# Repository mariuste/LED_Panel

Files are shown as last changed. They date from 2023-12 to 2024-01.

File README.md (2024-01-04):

# LED light panel with adjustable color temperature
# Project Parameters
Name: "LED light panel with adjustable color temperature"
Description: "USB-C powered LED Light with adjustable brigthness and color temperature"
Short Name: "LED Panel"
Github Name: "LED_Panel"
PCB Name: "LED_Panel"

# Description
/TODO/

# ToDos
- create requirements
- define critical components (MCU, poti, Mosfets, emc)
- define mechanical constraints (dimensios glass, mounting priciple, screw positios)
- create 3D Mockup
- create schematic
- create layout

# Specification for LED_board

## Usage
- plug in -> LED will go to last setting (maybe slight fade) if sw is on
- on/off switch integrated in poti 1
- turn poti 1 for adjusting brightness
- turn poti 2 for adjusting light color

## HMI
- Large Pot for brightness and on/off
- Small Poti for light color

## LEDs
- LEDs can be divided every 13mm; 608 LED per meter (304 per color); 22W per meter
- three rows of 130mm strips

## Core Function
- create soft light and adjust light color

## Software
- brightness and light color controlled via two PWM MOSFETs

### Fault handling
- not enough voltage/power from USB-C: light pattern to indicate error

## Software
- loop: read USB-PD for available power, read poti, set brightness and color

## Power concept
- LEDs: 22W/m -> 3 * 130mm * 22W = 8.58W // 715mA@12V -> with 80%DCDC: 686mA@15V / 515mA@20V
- USB-PD board set to 15V, >= 1.0A (15W)
- DC/DC to regulate 15V to 12V, 1A
- when switch is off-> reset USB PD

## Mechanics
- acryl from https://expresszuschnitt.de (170mm * 90mm * 4mm, rounded corner of 8mm radius)
- M4 mounting to enclosure
- M4 mounting for mounting plate (75 * 75)

# Part selection
- MCU: STM32L011F3U6TR
- Poti /w switch: P091S-FC20BR10K
- Poti /wo Switch: P091N-FC25BR10K
- LED: COB44-079  by LED24
- USB: UJC-HP2-3-SMT-TR

- Regulator: TPS62932DRLR
- Inductor: 7447709150

- MOSFET: SI1308EDL-T1-GE3
- LDO: NCP716MT30TBG

- USBPD: STUSB4500

obsolet (could replace DC/DC and MOSFET):
- LED-driver: TPS92200D2RXLR ? AL8861Y-13 ? IS31LT3350-V1SDLS2-TR

# Preliminary pinmapping
## USB-PD IC
- SDA PB7
- SCL PB6
- reset PD PA9 (OUT)
- alarm in PA10 (IN)

## Debuging (GPIOS)
- GPIO1 PC14
- GPIO2 PC15

## Debugging (SWD)
- SWDIO PA13
- SWCLK PA14

## Poti Readback (Vref: 1.224V)
- Poti1 PA0 (AIN0)
- Poti2 PA4 (AIN4)

## PWM outputs
- LED1 PA5 (TIM2_CH1)
- LED2 PA1 (TIM2_CH2)

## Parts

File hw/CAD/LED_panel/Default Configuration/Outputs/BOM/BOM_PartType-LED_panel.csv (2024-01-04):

Quantity | Designator | Type | Comment | Description | Manufacturer | Manufacturer Part Number | LibRef | Supplier 1 | Supplier Part Number 1
3 | C200, C201, C202 | Capacitor | C 4.7uF 0805 50V | CAP CER 4.7UF 50V X5R 0805 | Samsung Electro-Mechanics | CL21A475KBQNNNE | CAP_4.7uF_50V_0805 | Digi-Key | 1276-1248-1-ND
4 | C203, C301, C400, C402 | Capacitor | C 100nF 0402 50V | CAP CER 0.1UF 50V X7R 0402 | Murata Electronics | GRM155R71H104KE14J | CAP_100nF_50V_0402 | Digi-Key | 490-13342-1-ND
4 | C204, C205, C206, C300 | Capacitor | C 1uF 0402 25V | CAP CER 1UF 25V X5R 0402 | Taiyo Yuden | TMK105BJ105MV-F | CAP_1uF_25V_0402 | Digi-Key | 587-3245-1-ND
1 | C302 | Capacitor | C 100nF 0402 10V | CAP CER 0.1UF 10V X5R 0402 | Samsung Electro-Mechanics | CL05A104MP5NNNC | CAP_100nF_10V_0402 | Digi-Key | 1276-1443-1-ND
1 | C401 | Capacitor | C 10uF 0805 50V | CAP CER 10UF 50V X5R 0805 | Murata Electronics | GRM21BR61H106KE43K | CAP_10uF_50V_0805 | Digi-Key | 490-GRM21BR61H106KE43KTR-ND
1 | C403 | Capacitor | C 47pF 0402 25V | CAP CER 47PF 25V C0G/NP0 0402 | KEMET | C0402C470J3GAC7867 | CAP_47pF_25V_0402 | Digi-Key | 399-C0402C470J3GAC7867CT-ND
1 | C404 | Capacitor | C 33nF 0402 50V | CAP CER 0.033UF 50V X7R 0402 | Murata Electronics | GCM155R71H333KE02J | CAP_33nF_50V_0402 | Digi-Key | 490-GCM155R71H333KE02JTR-ND
1 | C405 | Capacitor | C 47uF 1206 25V | CAP CER 47UF 25V X5R 1206 | Murata Electronics | GRM31CR61E476ME44K | CAP_47uF_25V_1206 | Digi-Key | GRM31CR61E476ME44K
1 | D100 | Diode | BAS20LT3G | DIODE GP 200V 200MA SOT23-3 | onsemi | BAS20LT3G | D_LL_200V_200mA | Digi-Key | BAS20LT3GOSCT-ND
2 | D200, D201 | Diode, TVS | TVS 41V | TVS DIODE 22VWM 41VC 1610 | STMicroelectronics | ESDA25P35-1U1M | D_SCH_41V_35A | Digi-Key | 497-16913-1-ND
1 | D202 | Diode, TVS | TVS_4 5V | TVS DIODE 5VWM 12.5VC SOT23-6 | Comchip Technology | CPDT6-5V0UPC-HF | D_TVS_U4_12V5 | Digi-Key | 641-1829-1-ND
2 | D203, D204 | Diode, LED | LED G | LED GREEN DIFFUSED 0603 SMD | OSRAM Opto Semiconductors Inc. | LT Q39G-Q1OO-25-1 | D_LED_Green_0603 | Digi-Key | 475-3442-1-ND
1 | D205 | Diode, LED | LED R | LED RED DIFFUSED 0603 SMD | OSRAM Opto Semiconductors Inc. | LS Q976-NR-1 | D_LED_Red_0603 | Digi-Key | 475-2512-1-ND
1 | IC200 | IC, Regulator | NCP716MT30TBG | IC REG LINEAR 3V 80MA 6WDFN | onsemi | NCP716MT30TBG | IC_Reg_NCP716MT30TBG | Digi-Key | 488-NCP716MT30TBGTR-ND
1 | IC201 | IC | STUSB4500 | IC USB CONTROLLER I2C 24QFN | STMicroelectronics | STUSB4500QTR | IC_STUSB4500 | Digi-Key | 497-18060-2-ND
1 | IC300 | IC, MCU | STM32L011F3U6 | IC MCU 32BIT 8KB FLASH 20UFQFPN | STMicroelectronics | STM32L011F3U6TR | IC_MCU_STM32L011F3U6 | Digikey | 497-18800-2-ND
1 | IC400 | IC, Regulator | TPS62932 | IC REG BUCK ADJ 2A SOT583 | Texas Instruments | TPS62932DRLR | IC_Reg_TPS62932DRLR | Digi-Key | 296-TPS62932DRLRTR-ND
1 | J200 | Connector | USB_C PWR | TYPE C, 20 VDC, 3 A, RIGHT ANGLE | CUI Devices | UJC-HP2-3-SMT-TR | J_USB-C_3 | Digi-Key | 2223-UJC-HP2-3-SMT-TR-ND
1 | J300 | Connector | 5x2 | CONN HEADER SMD 10POS 1.27MM | Sullins Connector Solutions | GRPB052VWQS-RC | J_MH5x2_1.27 | Digi-Key | S9012E-05-ND
1 | L200 | Inductor | L 1.2uH 3.9A | FIXED IND 1.2UH 3.9A 36 MOHM SMD | Würth Elektronik | 74438336012 | L_1.2uH_3.9A | Digi-Key | 732-5694-1-ND
2 | L201, L202 | Inductor, Ferrite | L Ferrite 100R 4A | FIXED IND 100 4000MA 1206 | Eaton - Electronics Division | MFBM1V3216-101-R | L_100R_4A | Digi-Key | 283-MFBM1V3216-101-RCT-ND
1 | L400 | Inductor | L 15uH 6.5A | FIXED IND 15UH 6.5A 26 MOHM SMD | Würth Elektronik | 7447709150 | L_15uH_6.5A | Digi-Key | 732-7447709150TR-ND
2 | P100, P101 | Transistor | P NMOS 30V 600mA | MOSFET N-CH 30V 600MA SC70-3 | Vishay Siliconix | SI1302DL-T1-E3 | P_NCH_30V_280mW | Digi-Key | SI1302DL-T1-E3CT-ND
1 | P102 | Transistor | P_NCH_50V_150mW | MOSFET N-CH 50V 200MA UMT3F | Rohm Semiconductor | RU1J002YNTCL | P_NCH_50V_150mW | Digi-Key | RU1J002YNTCLCT-ND
1 | P200 | Transistor | P PMOS 30V 6A | MOSFET P-CH 30V 6A SOT23F | Toshiba Semiconductor and Storage | SSM3J372R,LF | P_PCH_30V_1W | Digi-Key | SSM3J372RLFCT-ND
4 | R100, R101, R102, R103 | Resistor | R 180R 0603 | RES 180 OHM 1% 1/10W 0603 | Stackpole Electronics Inc | RMCF0603FT180R | R_180R_0603 | Digi-Key | RMCF0603FT180RCT-ND
5 | R104, R106, R201, R207, R213 | Resistor | R 1k8 0402 | RES 1.8K OHM 1% 1/16W 0402 | Stackpole Electronics Inc | RMCF0402FT1K80 | R_1k8_0402 | Digi-Key | RMCF0402FT1K80CT-ND
12 | R105, R107, R108, R110, R208, R209, R210, R211, R214, R215, R301, R404 | Resistor | R 7k15 0402 | RES 7.15K OHM 1% 1/16W 0402 | Stackpole Electronics Inc | RMCF0402FT7K15 | R_7k15_0402 | Digi-Key | RMCF0402FT7K15CT-ND
7 | R109, R202, R206, R212, R300, R302, R403 | Resistor | R 100k 0402 | RES 100K OHM 5% 1/16W 0402 | YAGEO | RC0402JR-07100KL | R_100k_0402 | Digi-Key | 311-100KJRCT-ND
5 | R111, R204, R303, R304, R305 | Resistor | R 100R 0402 | RES 100 OHM 1% 1/16W 0402 | Stackpole Electronics Inc | RMCF0402FT100R | R_100R_0402 | Digi-Key | RMCF0402FT100RCT-ND
9 | R200, R203, R205, R216, R217, R218, R400, R401, R402 | Resistor | R 0R0 0402 | RES 0 OHM JUMPER 1/16W 0402 | Stackpole Electronics Inc | RMCF0402ZT0R00 | R_0R0_0402 | Digi-Key | RMCF0402ZT0R00CT-ND
1 | RT100 | other, Poti | 10k | POT 10K OHM 1/20W PLASTIC LINEAR | TT Electronics/BI | P091S-FC20BR10K | RT_10k_SW_V | Digi-Key | 987-1283-ND
1 | RT101 | other, Poti | 10k | POT 10K OHM 1/20W PLASTIC LINEAR | TT Electronics/BI | P091N-FC25BR10K | RT_10k_V | Digi-Key | 987-1279-ND
3 | X100, X101, X102 | other | LED Strip | revoART, 12V COB LED Streifen - einstellbare Farbtemperatur - alle 1,3cm teilbar - 10mm breit | revoART | COB44-076 | LED_Strip_2WH_131mm | LED24 | COB44-076

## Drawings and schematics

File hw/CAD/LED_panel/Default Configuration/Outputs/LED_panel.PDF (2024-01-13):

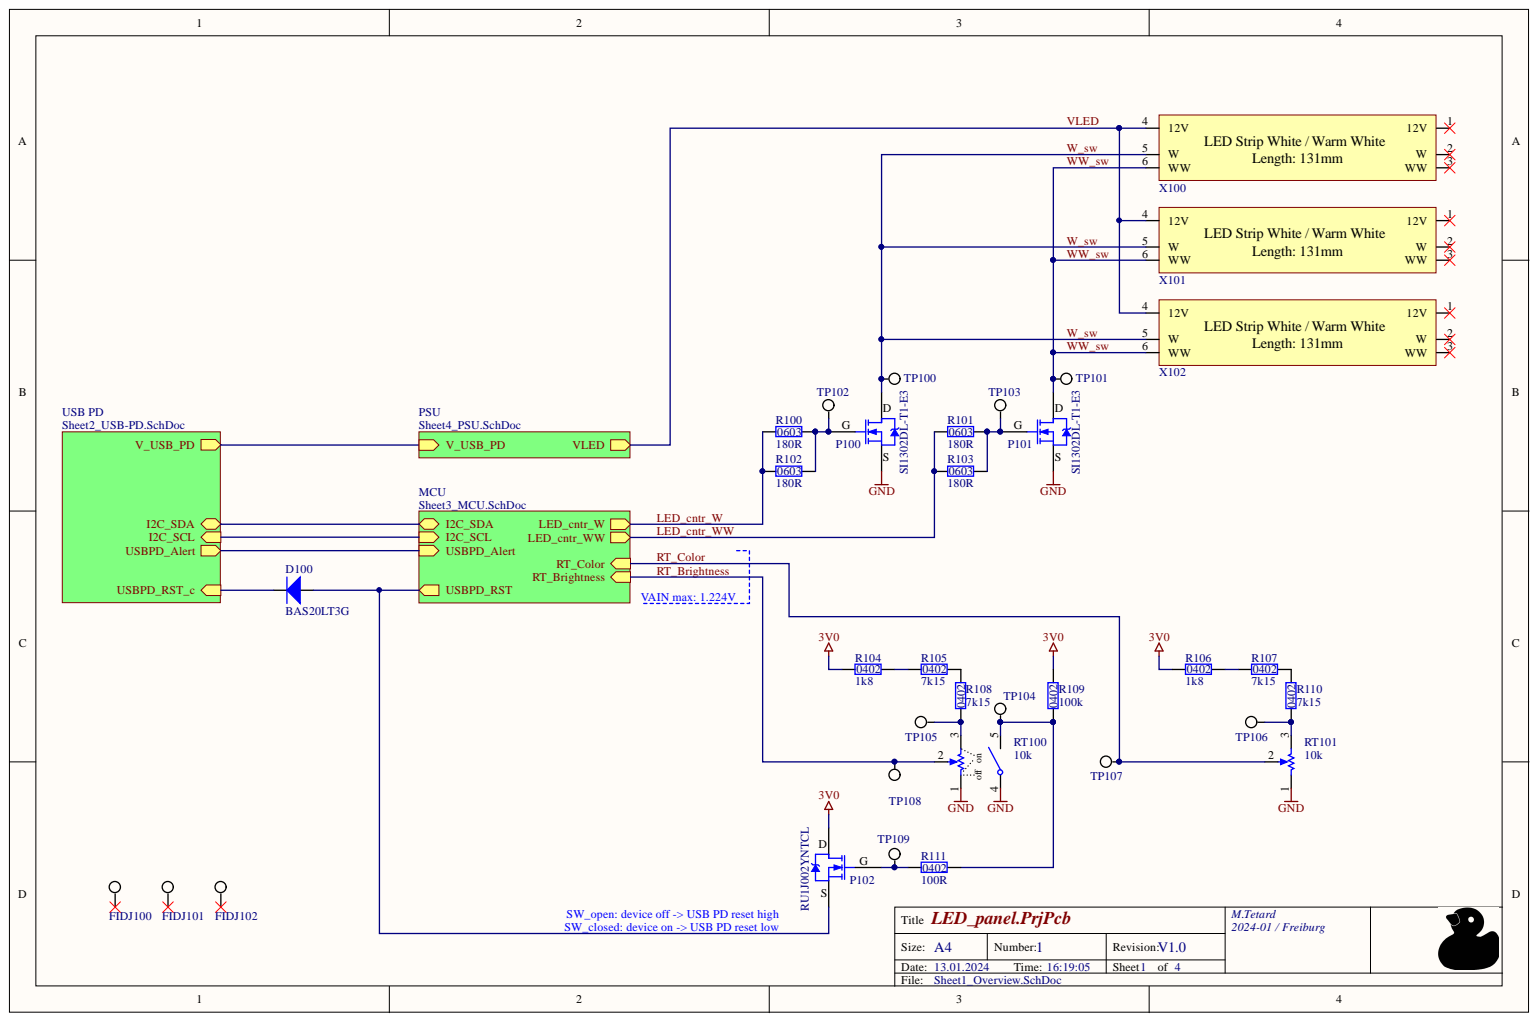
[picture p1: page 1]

W_sw | | W 5
WW_sw | | | WW 6

LED Strip White / Warm White

W_sw

RT_Brightness

VAIN max: 1.224V

SW_open: device off -> USB PD reset high
SW_closed: device on -> USB PD reset low

LED_panel.PrjPcb Title | M.Tetard 2024-01 / Freiburg

A4 Size: | 1 Number: | V1.0 Revision:
Date: 13.01.2024 Time: 16:19:05 | | Sheet of

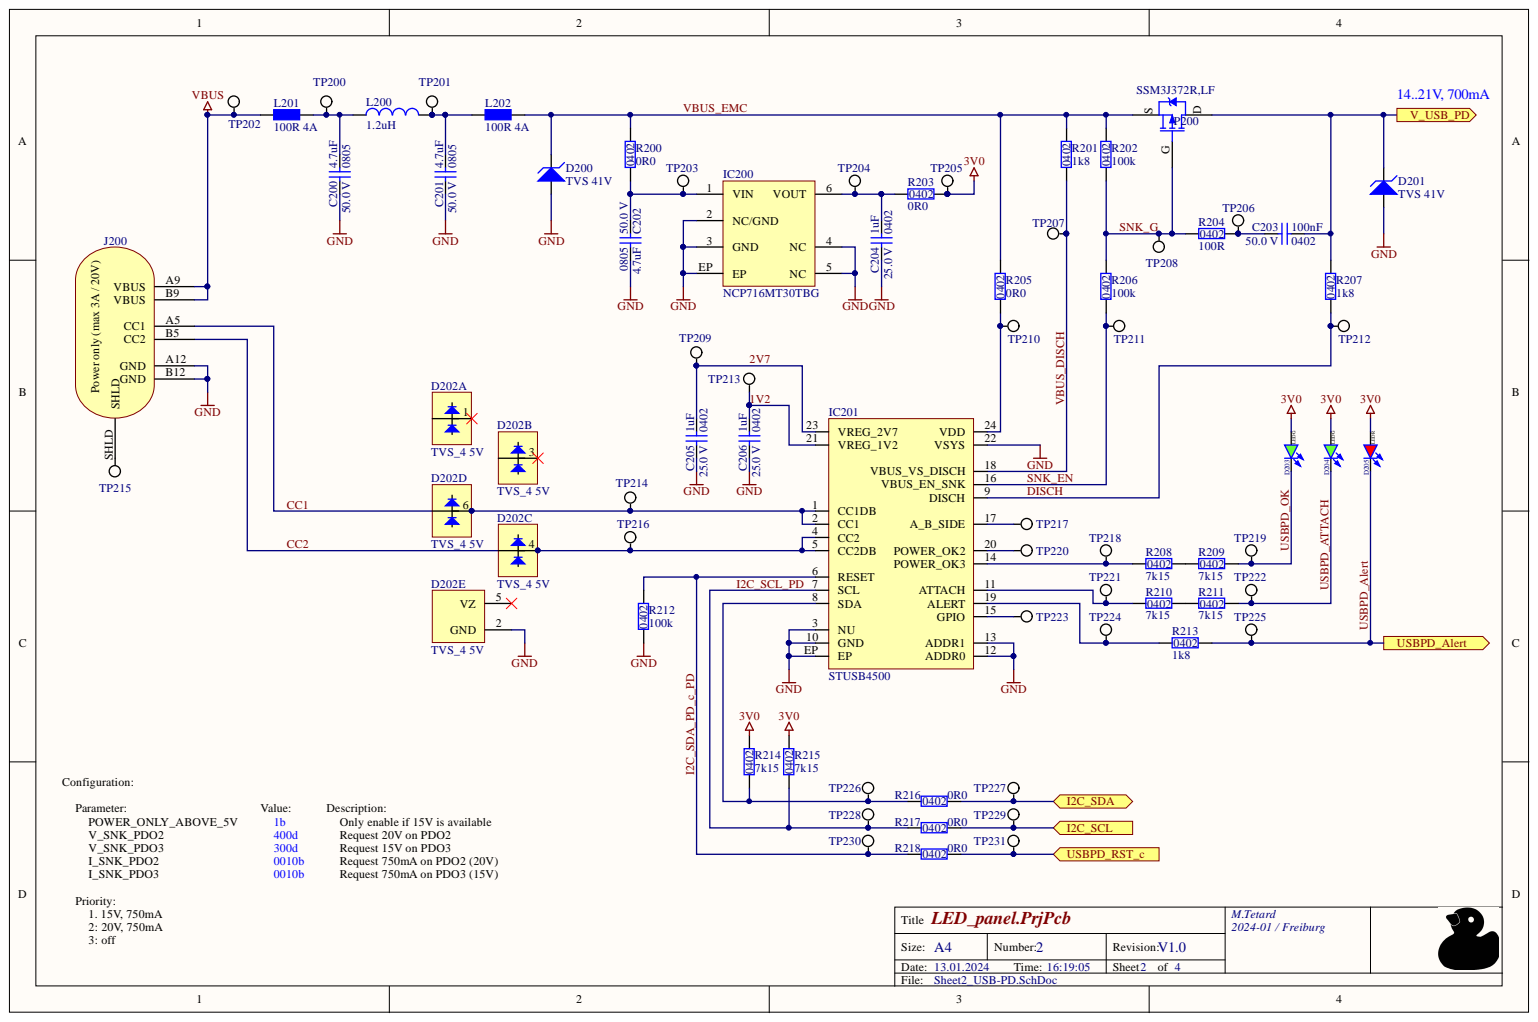
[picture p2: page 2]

NC/GND 2 | 0402

RESET 6

I2C_SCL_PD

SDA 8

GND 10

Description:
Only enable if 15V is available

LED_panel.PrjPcb Title | M.Tetard 2024-01 / Freiburg

A4 Size: | 2 Number: | V1.0 Revision:

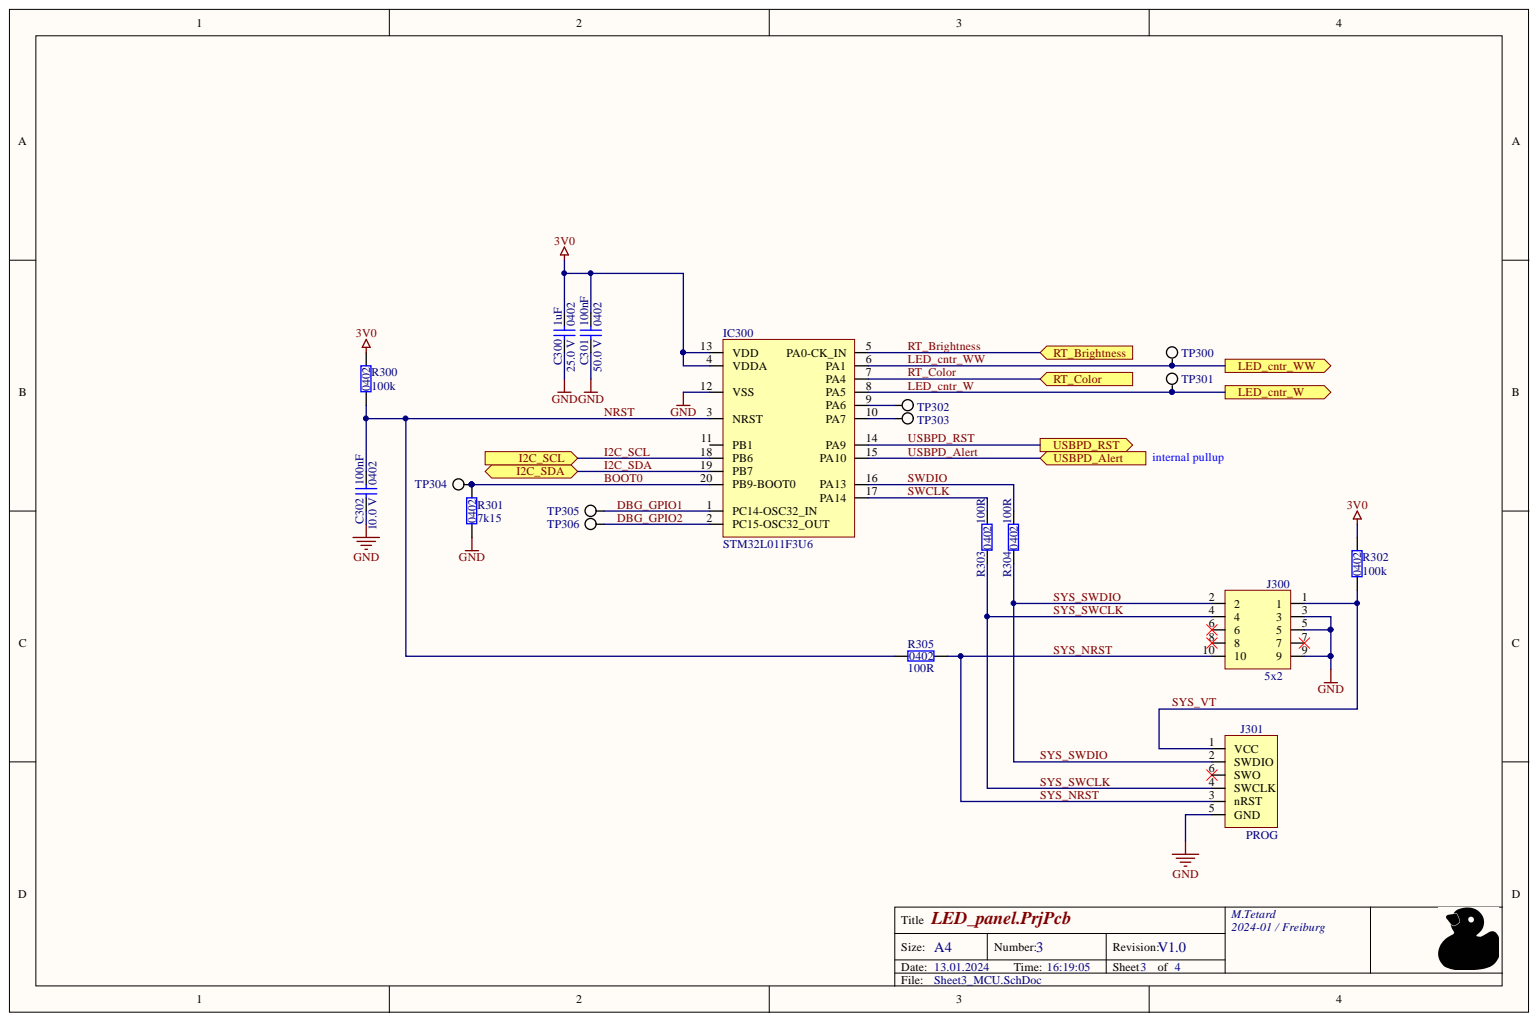
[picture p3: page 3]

I2C_SCL I2C_SCL I2C_SDA I2C_SDA BOOT0 | PB1 11 PA9 PA10 PA13 PA14 | 14 15 16

PC14-OSC32_IN 1 PC15-OSC32_OUT 2 | | 17 | SWCLK

SYS_SWCLK

SYS_NRST

SYS_SWDIO | SYS_VT | GND

SWDIO 2

LED_panel.PrjPcb Title | M.Tetard 2024-01 / Freiburg

A4 Size: | 3 Number: | V1.0 Revision:

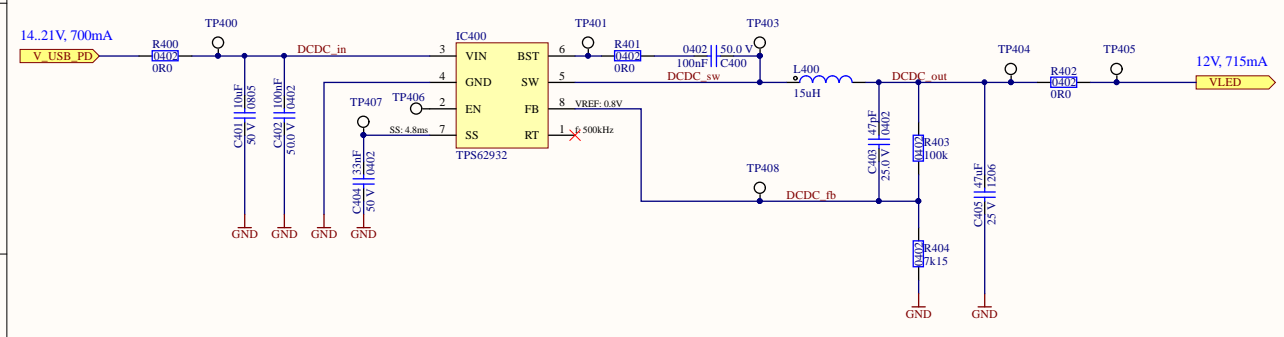
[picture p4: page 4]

7 | | 1 | f: 500kHz TP4 0 8 DCDC_fb

LED _p T i t l e | M.Tet a rd 2 0 2 4-0 1 / F rei b u rg

A4 Size: | N umber: | Rev i s i o n :

3.0 1.2 T ime: : : | | Sheet o f

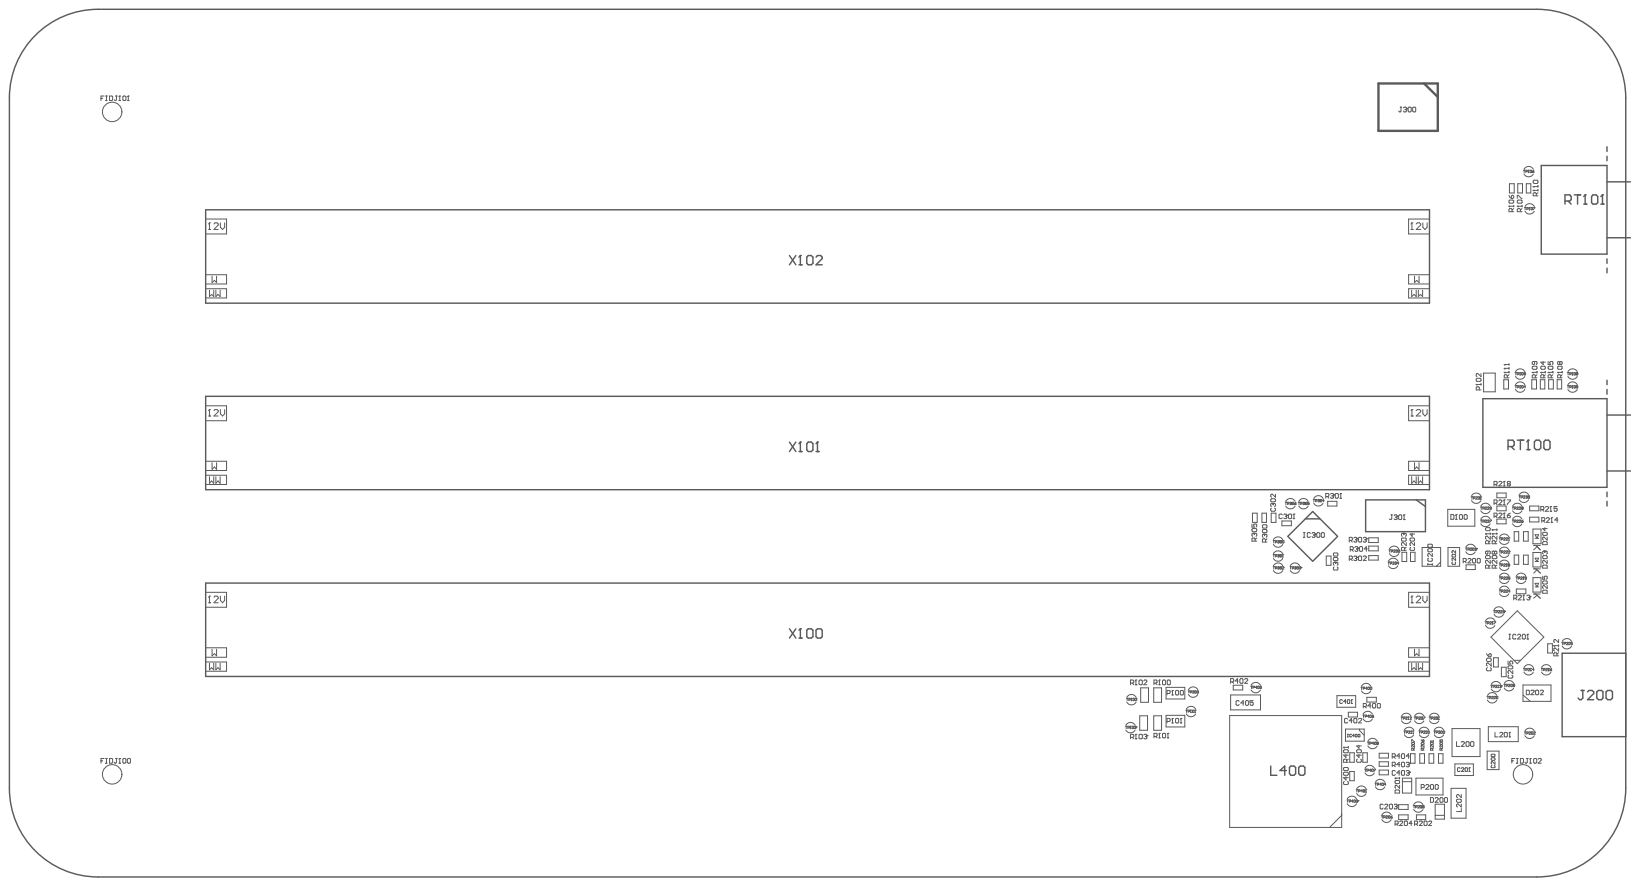
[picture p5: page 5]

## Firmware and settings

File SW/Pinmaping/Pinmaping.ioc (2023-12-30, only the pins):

Mcu.UserName=STM32L011F3Ux
PA0-CK_IN.Signal=ADC_IN0
PA1.Signal=S_TIM2_CH2
PA10.Signal=GPIO_Input
PA13.Signal=SYS_SWDIO
PA14.Signal=SYS_SWCLK
PA4.Signal=ADC_IN4
PA5.Signal=S_TIM2_CH1
PA9.Signal=GPIO_Output
PB6.Signal=I2C1_SCL
PB7.Signal=I2C1_SDA
PC14-OSC32_IN.Signal=GPIO_Input
PC15-OSC32_OUT.Signal=GPIO_Input

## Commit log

2023-12-26 designed device
2023-12-27 initial draft
    [LED_panel.PrjPcb, Sheet1_Overview.SchDoc, Sheet2_USB-PD.SchDoc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]
2023-12-27 Initial schematic draft
    [LED_panel.PrjPcb, Sheet1_Overview.SchDoc, Sheet2_USB-PD.SchDoc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]
2023-12-28 first draft of schematic ready (minus LED strip)
    [Sheet1_Overview.SchDoc, Sheet2_USB-PD.SchDoc, Sheet3_MCU.SchDoc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]
2023-12-28 schematic finished, import to PCB
    [Sheet1_Overview.SchDoc, Sheet3_MCU.SchDoc]
2023-12-29 placement: USB PD finished
    [Sheet1_Overview.SchDoc, Sheet2_USB-PD.SchDoc]
2023-12-29 placed regulators
2023-12-29 placed poti contr.
    [Sheet1_Overview.SchDoc]
2023-12-29 layout draft finished
    [Sheet1_Overview.SchDoc, Sheet3_MCU.SchDoc, Sheet4_PSU.SchDoc]
2023-12-29 Layout finished
    [LED_panel.PrjPcb]
2024-01-04 finalized layout, ready to export
    [LED_panel.PrjPcb]
2024-01-04 finished layout, performed export
    [BOM_PartType-LED_panel.csv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]
2024-01-05 modify outjob
    [LED_panel.PrjPcb]
2024-01-13 clean up, ordered
    [LED_panel.PrjPcb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]
